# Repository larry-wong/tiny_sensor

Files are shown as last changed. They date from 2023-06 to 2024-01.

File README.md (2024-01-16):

基于 ESP32 的家庭智能传感器，搭配 [Home Assistant](https://www.home-assistant.io/) 项目实现家自动化。

小巧的身材上集成温湿度 / 光照度 / 人体存在传感器和红外发射管。

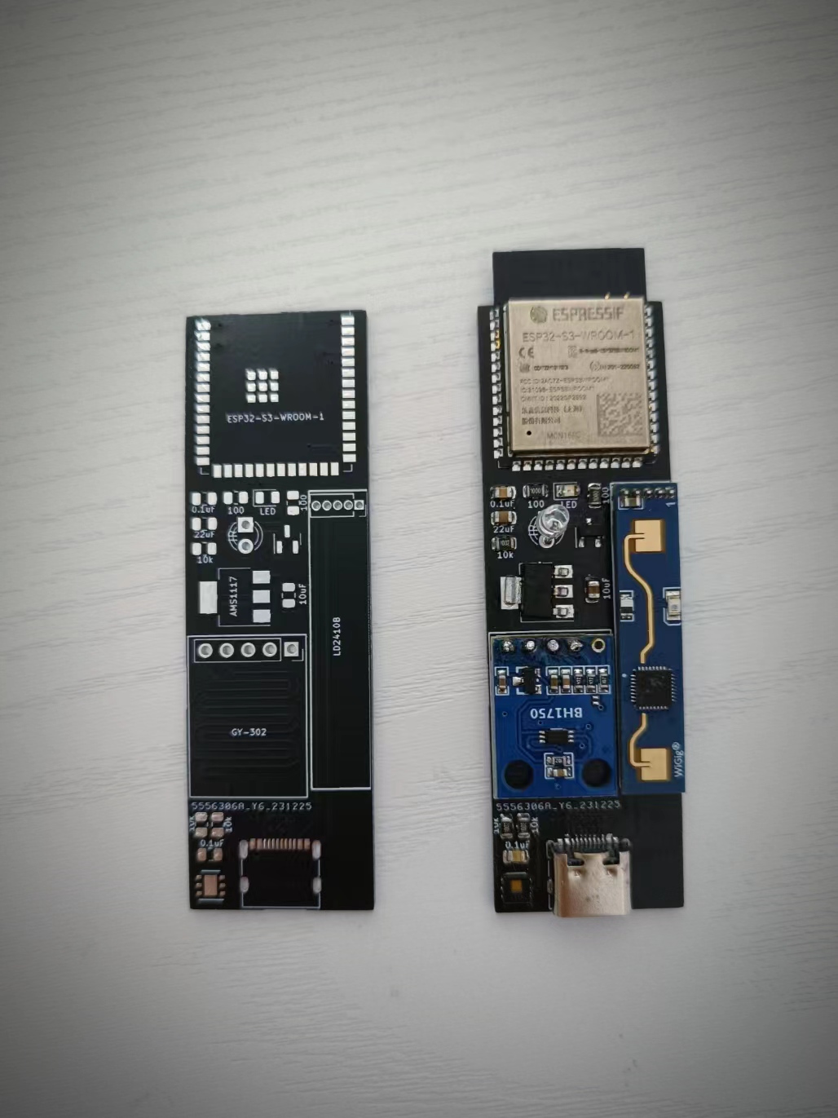
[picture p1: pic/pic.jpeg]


## 硬件设计
* 主控选用 ESP32-S3-WROOM-1
* 温湿度传感器选用 HDC1080
* 光照度传感器选用 GY-302 模块
* 人体存在传感器选用 LD2410B 模块
* 红外发射选用 3mm 发射管
* 状态灯选用贴片发光二极管
* 采用 typec 口供电 / 烧写程序，针脚对应关系：

    | typec | esp32 | 备注 |
    |---|---|---|
    | GND (A1, A12, B1, B12) | GND | 接地 |
    | VBUS (A4, A9, B4, B9) | | 5V |
    | CC1 (A5), CC2 (B5) | GPIO0 | 烧写固件时需接地 |
    | D+ (A6, B6) | GPIO43 | TX |
    | D- (A7, B7) | GPIO44 | RX |

## 电路设计
原理图及 PCB 使用 kicad 绘制，项目文件见 circut 目录（依赖 [ESPRESSIF 官方库](https://github.com/espressif/kicad-libraries)）。

* 所有贴片元件均采用 0805 封装尺寸
* 焊接时可多留一些红外管引脚，以调整发射方向
* 不需要的传感器可留空
* 由于不同颜色发光二极管的压降不同，在 R3 为 100 欧姆时 D2 采用红色发光二极管效果较好，采用黄色发光二极管时亮度较低。若要使用其他颜色发光二极管可自行计算 R3 阻值。

## 固件设计
固件使用 [ESPHome](https://esphome.io/) 搭建，配置文件见 esphome 目录。

* 暴露以下传感器至 Home Assistant:
    * 一个温度传感器
    * 一个湿度传感器
    * 一个光照度传感器
    * 一个人体存在二元传感器
    * 一个人体存在距离传感器
    * 一个可开关的 LED 灯（复用状态灯）
* 项目中对红外管的使用比较客制化，使用自定义的 MQTT 消息驱动。建议改用 [Remote Transmitter](https://esphome.io/components/remote_transmitter.html) 或自行修改。

## 应用参考
接入 Home Assistant 后，可使用暴露出的传感器实现一些家庭自动化，例如：
* 使用人体存在传感器配合光照度传感器控制灯
* 甚至可配合人体存在距离传感器大致确定人体位置后控制不同的灯
* 使用人体存在传感器配合温度传感器控制空调制冷 / 加热 / 关闭
* 使用湿度传感器控制加湿器
* 使用 LED 指示报警信息（电量低，扫地机集尘盒满等）
* 使用红外管控制空调 / 电视 / 浴霸等传统电器
* ……

## 捐赠
如果此项目对你有帮助，可扫描下方二维码请我喝杯咖啡 :)

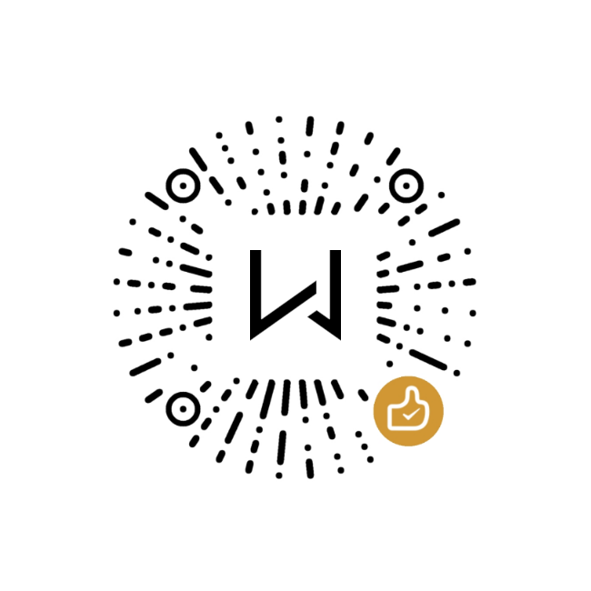
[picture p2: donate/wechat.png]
使用微信扫一扫
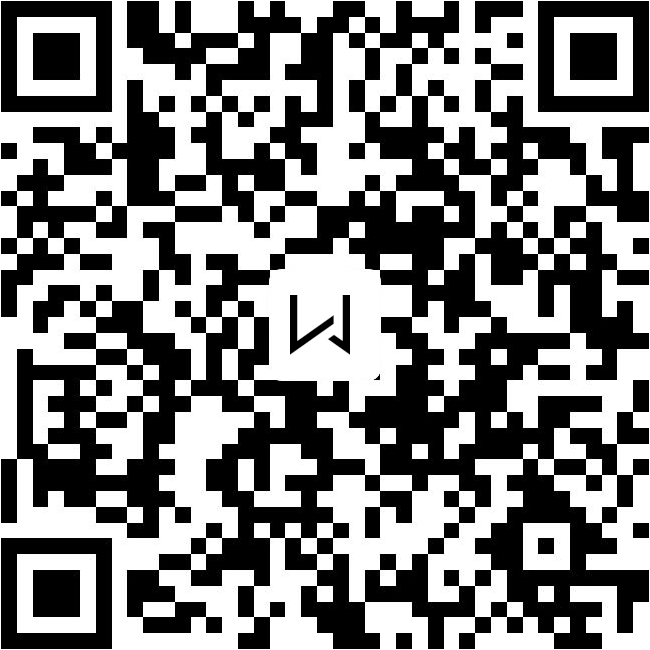
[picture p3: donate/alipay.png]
使用支付宝扫一扫
&nbsp;&nbsp;&nbsp;&nbsp;&nbsp;&nbsp;&nbsp;&nbsp;  &nbsp;&nbsp;&nbsp;&nbsp;&nbsp;&nbsp;&nbsp;&nbsp;&nbsp;&nbsp;&nbsp;&nbsp;&nbsp;&nbsp;&nbsp;&nbsp;

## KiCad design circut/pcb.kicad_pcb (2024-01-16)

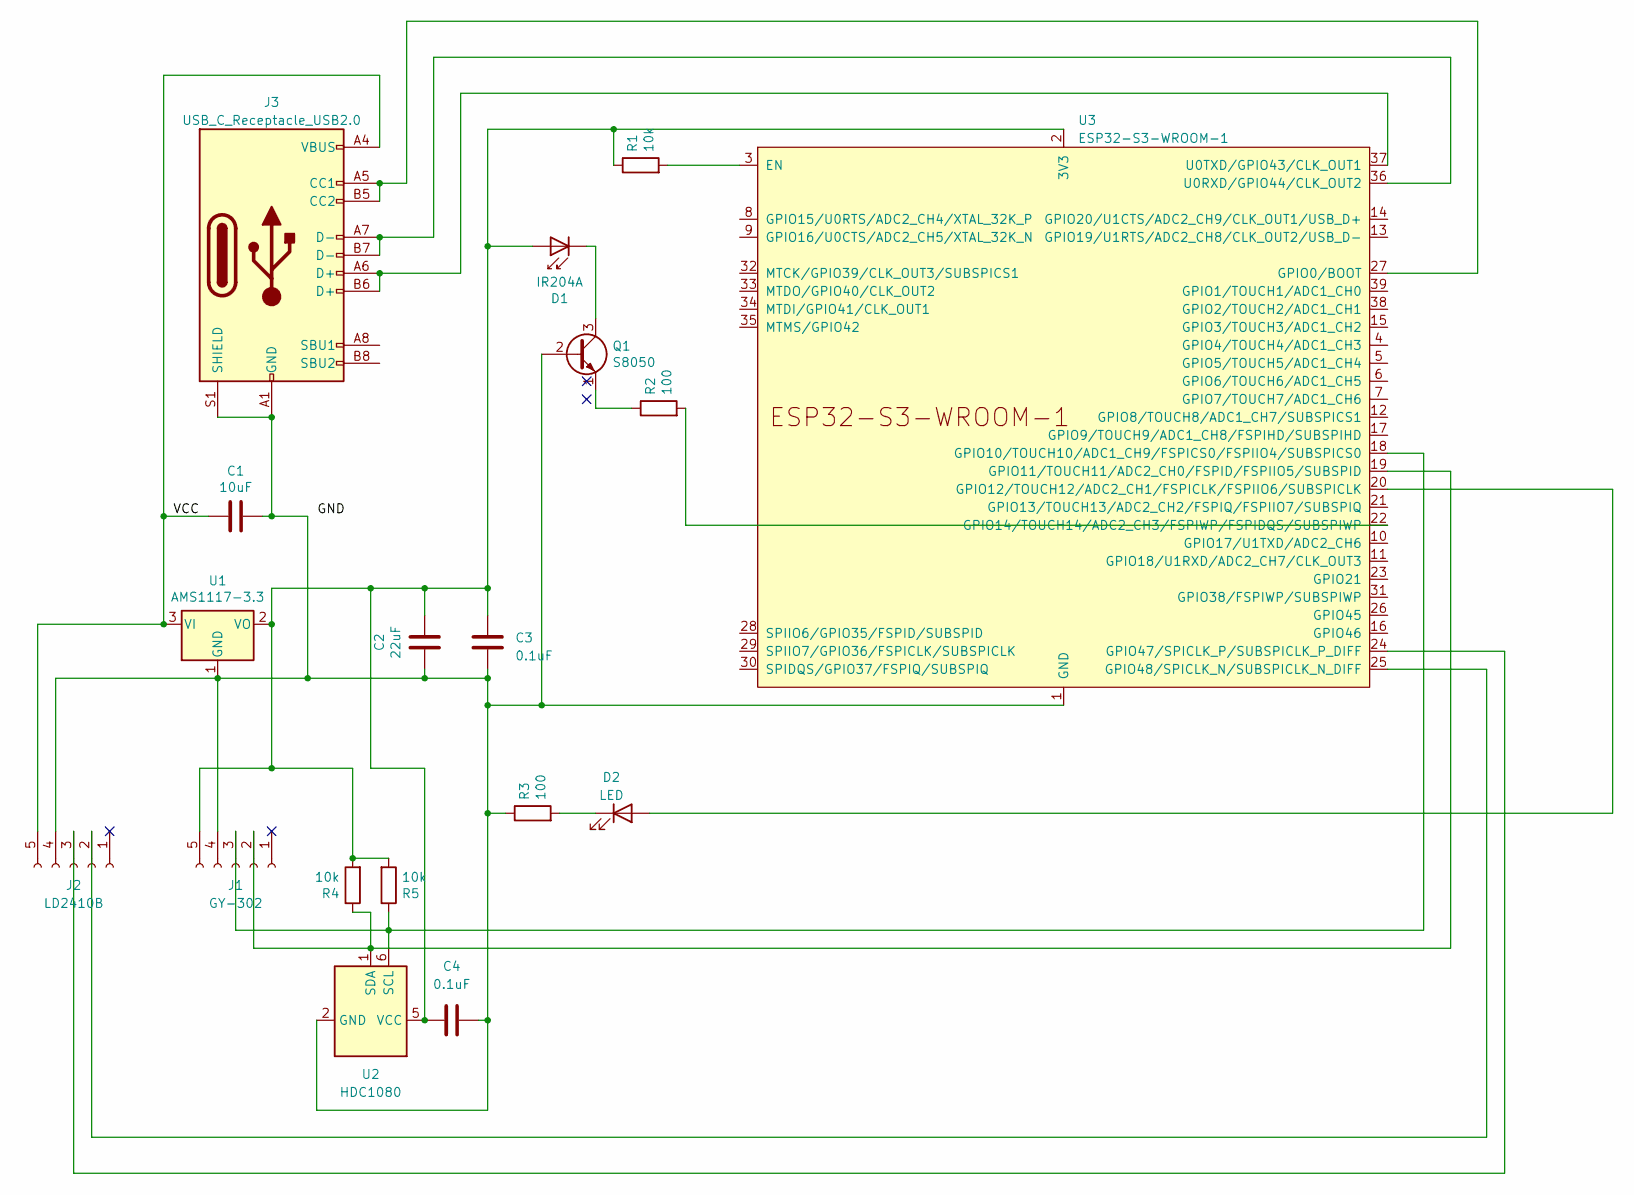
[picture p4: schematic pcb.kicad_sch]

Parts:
C1: 10uF; C_0805_2012Metric
C2: 22uF; C_0805_2012Metric
C3, C4: 0.1uF; C_0805_2012Metric
D1: IR204A; LED_D3.0mm_IRBlack
D2: LED; D_0805_2012Metric
J1: GY-302; PinSocket_1x05_P2.54mm_Vertical
J2: LD2410B; PinSocket_1x05_P1.27mm_Vertical
J3: USB_C_Receptacle_USB2.0; USB_C_Receptacle_G-Switch_GT-USB-7010ASV
Q1: S8050; SOT-23
R1, R4, R5: 10k; R_0805_2012Metric
R2, R3: 100; R_0805_2012Metric
U1: AMS1117-3.3; SOT-223-3_TabPin2
U2: HDC1080; Texas_PWSON-N6
U3: ESP32-S3-WROOM-1

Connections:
/VCC: C1.2, J2.5, J3.A4 (VBUS), J3.A9 (VBUS), J3.B4 (VBUS), J3.B9 (VBUS), U1.3 (VI)
unnamed: C2.1, C3.1, C4.1, D1.2 (A), J1.5, R1.1, R4.2, R5.2, U1.2 (VO), U2.5 (VCC), U3.2 (3V3)
unnamed: D1.1 (K), Q1.3 (C)
unnamed: D2.2 (A), U3.20 (GPIO12/TOUCH12/ADC2_CH1/FSPICLK/FSPIIO6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)
unnamed: D2.1 (K), R3.2
unnamed: J1.2, R4.1, U2.1 (SDA), U3.19 (GPIO11/TOUCH11/ADC2_CH0/FSPID/FSPIIO5/S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)
unnamed: J1.3, R5.1, U2.6 (SCL), U3.18 (GPIO10/TOUCH10/ADC1_CH9/FSPICS0/FSPIIO4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)
unnamed: C1.1, C2.2, C3.2, C4.2, J1.4, J2.4, J3.A1 (GND), J3.A12 (GND), J3.B1 (GND), J3.B12 (GND), J3.S1 (SHIELD), Q1.2 (B), R3.1, U1.1 (GND), U2.2 (GND), U3.1 (GND), U3.40 (GND), U3.41 (GND)
unnamed: J2.2, U3.25 (GPIO48/SPICLK_N/SUBSPICLK_N_DIFF)
unnamed: J2.3, U3.24 (GPIO47/SPICLK_P/SUBSPICLK_P_DIFF)
unnamed: J3.A5 (CC1), J3.B5 (CC2), U3.27 (GPIO0/BOOT)
unnamed: Q1.1 (E), R2.1
unnamed: R1.2, U3.3 (EN)
unnamed: R2.2, U3.22 (GPIO14/TOUCH14/ADC2_CH3/FSPIWP/FSPIDQS/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)
unnamed: J3.A7 (D-), J3.B7 (D-), U3.36 (U0RXD/GPIO44/CLK_OUT2)
unnamed: J3.A6 (D+), J3.B6 (D+), U3.37 (U0TXD/GPIO43/CLK_OUT1)

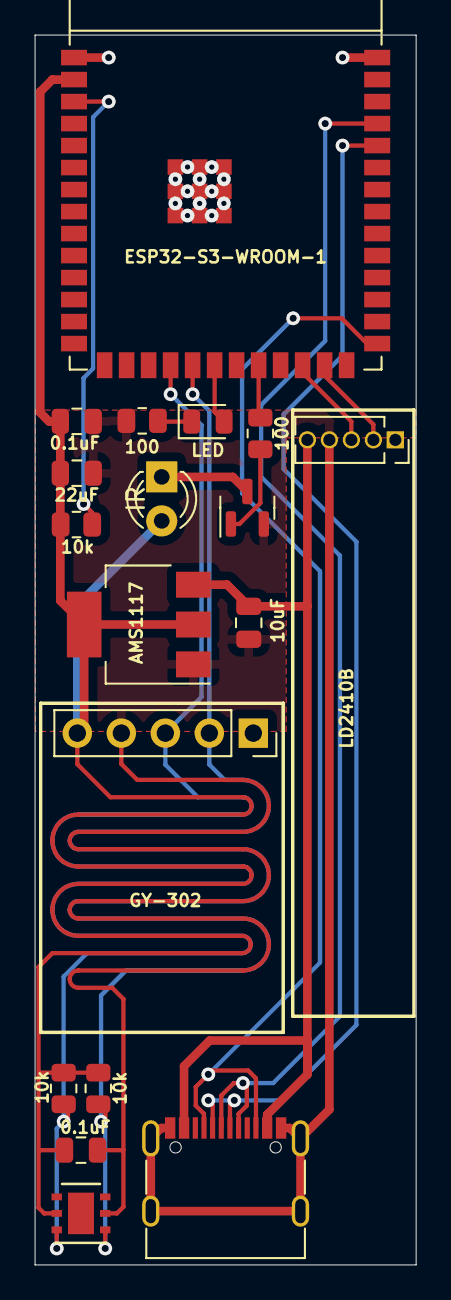
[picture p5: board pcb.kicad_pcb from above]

Board: 2 copper layers, 22.0 x 71.0 mm, 18 parts (0 on the bottom side), 16 nets.

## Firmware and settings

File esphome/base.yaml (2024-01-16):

esphome:
  name: $name
  friendly_name: $friendly_name
  includes:
    - ir_sender.h
  libraries:
    - IRremoteESP8266
  min_version: 2023.12.6

esp32:
  board: esp32-s3-devkitc-1
  framework:
    type: arduino
  variant: esp32s3

# Enable logging
logger:

# Enable Home Assistant API
api:
  encryption:
    key: !secret api_key

ota:
  password: !secret ota_password

wifi:
  ssid: !secret wifi_ssid
  password: !secret wifi_password
  manual_ip:
    static_ip: $ip_addr
    gateway: !secret gateway
    subnet: !secret subnet
  power_save_mode: none
  output_power: 20.5

mqtt:
  broker: !secret mqtt_broker
  port: !secret mqtt_port
  username: !secret mqtt_username
  password: !secret mqtt_password
  discovery: false
  on_message:
    topic: /ir/send/$name
    then:
      - light.turn_on: light_status
      - delay: 0s
      - lambda: |-
          send_ir(&x[0], x.size());
      - light.turn_off: light_status

i2c:
  sda: GPIO11
  scl: GPIO10

uart:
  baud_rate: 256000
  tx_pin: GPIO47
  rx_pin: GPIO48

ld2410:

sensor:
  - platform: bh1750
    name: Immunination
  - platform: hdc1080
    temperature:
      name: Temperature
    humidity:
      name: Humidity
  - platform: ld2410
    detection_distance:
      name: Detection Distance

binary_sensor:
  - platform: ld2410
    has_target:
      name: Presence

switch:
  - platform: ld2410
    bluetooth:
      name: ld2410 Bluetooth

number:
  - platform: ld2410
    timeout:
      name: Presence Timeout
    max_move_distance_gate:
      name: Max Move Distance Gate
    max_still_distance_gate:
      name: Max Still Distance Gate
    g0:
      move_threshold:
        name: g0 Move Threshold
      still_threshold:
        name: g0 Still Threshold
    g1:
      move_threshold:
        name: g1 Move Threshold
      still_threshold:
        name: g1 Still Threshold
    g2:
      move_threshold:
        name: g2 Move Threshold
      still_threshold:
        name: g2 Still Threshold
    g3:
      move_threshold:
        name: g3 Move Threshold
      still_threshold:
        name: g3 Still Threshold
    g4:
      move_threshold:
        name: g4 Move Threshold
      still_threshold:
        name: g4 Still Threshold
    g5:
      move_threshold:
        name: g5 Move Threshold
      still_threshold:
        name: g5 Still Threshold
    g6:
      move_threshold:
        name: g6 Move Threshold
      still_threshold:
        name: g6 Still Threshold
    g7:
      move_threshold:
        name: g7 Move Threshold
      still_threshold:
        name: g7 Still Threshold
    g8:
      move_threshold:
        name: g8 Move Threshold
      still_threshold:
        name: g8 Still Threshold

light:
  - platform: status_led
    id: light_status
    name: Status
    pin: GPIO12
    icon: "mdi:led-outline"

custom_component:
  - lambda: |-
      auto ir_sender = new IRSender();
      return {ir_sender};

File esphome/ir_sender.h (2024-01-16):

#include "esphome.h"
#include <IRremoteESP8266.h>
#include <IRsend.h>

const uint16_t IR_PIN = 14;

// For IR
IRsend irsend(IR_PIN);
// End for IR

// convert single hex char to dec
uint8_t hex2dec(const char hex) {
    if (hex >= 48 && hex <= 57) { // 0 ~ 9
        return hex - 48;
    } else if (hex >= 65 && hex <= 70) { // A ~ F
        return hex - 55;
    } else if (hex >= 97 && hex <= 102) { // a ~ f
        return hex - 87;
    } else {
        return 0;
    }
}

// convert multi hex chars to dec
uint16_t hex2dec(const char* payload, const uint8_t len) {
    uint16_t res = 0;
    for (uint8_t i = 0; i < len; i++) {
        res = res * 16 + hex2dec(payload[i]);
    }
    return res;
}

void send_ir(const char* payload, const uint16_t length) {
    /* 
        payload format:
        ----------------------------------
        | field       | length  | offset |
        ----------------------------------
        ----------------------------------
        | repeat      | 1 byte  | 0      |
        ----------------------------------
        | header mark | 3 bytes | 1      |
        | header gap  | 3 bytes | 4      |
        ----------------------------------
        | one mark    | 3 bytes | 7      |
        | one space   | 3 bytes | 10     |
        ----------------------------------
        | zero mark   | 3 bytes | 13     |
        | zero space  | 3 bytes | 16     |
        ----------------------------------
        | footer mark | 3 bytes | 19     |
        | gap?        | 4 bytes | 22     |
        ----------------------------------
        | data        |         | 22 / 26|
        ----------------------------------
    */

    const uint8_t repeat = hex2dec(payload + 0, 1);
    const uint16_t headermark = hex2dec(payload + 1, 3);
    const uint16_t headerspace = hex2dec(payload + 4, 3);
    const uint16_t onemark = hex2dec(payload + 7, 3);
    const uint16_t onespace = hex2dec(payload + 10, 3);
    const uint16_t zeromark = hex2dec(payload + 13, 3);
    const uint16_t zerospace = hex2dec(payload + 16, 3);
    const uint16_t footermark = hex2dec(payload + 19, 3);
    uint16_t gap = 0;
    uint8_t dataoffset = 22;
    if (repeat > 0) {
        gap = hex2dec(payload + 22, 4);
        dataoffset = 26;
    }

    const uint8_t datalength = (length - dataoffset) / 2;
    uint8_t data[datalength];
    for (uint8_t i = 0; i < datalength; i ++) {
        data[i] = hex2dec(payload + dataoffset + i * 2, 2);
    }

    // send ir signal ...
    irsend.sendGeneric(headermark, headerspace, onemark, onespace,
                       zeromark, zerospace, footermark, gap,
                       data, datalength, 38, false, repeat, 50);
}

class IRSender : public Component {
    public:
        void setup() override {

            // start ir send module
            irsend.begin();
        }
};
